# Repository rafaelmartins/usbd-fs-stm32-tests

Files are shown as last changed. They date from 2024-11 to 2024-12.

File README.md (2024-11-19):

# usbd-fs-stm32-tests

Integration tests for [usbd-fs-stm32](https://github.com/rafaelmartins/usbd-fs-stm32) library.

This repository contains the whole infrastructure required to test the library in real hardware:

- Raspberry PI Hat [PCB](./pcb) and [3D models](./3d-models)
- [Test Runner](./runner)
- [Test Firmware](./firmware) *(TODO)*
- [Github Action](./action.yml) used by main [usbd-fs-stm32 repository](https://github.com/rafaelmartins/usbd-fs-stm32) *(TODO)*

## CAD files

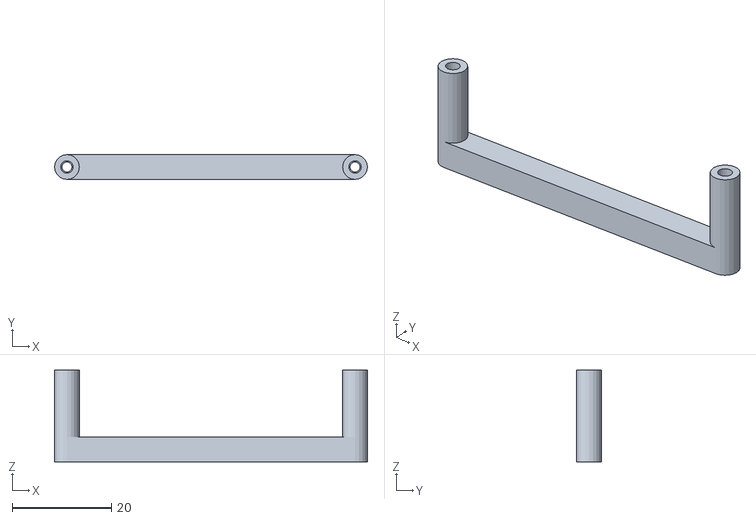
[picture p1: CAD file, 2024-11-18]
3d-models/pcb-rpi-support.stl
63.0 x 5.00 x 18.5

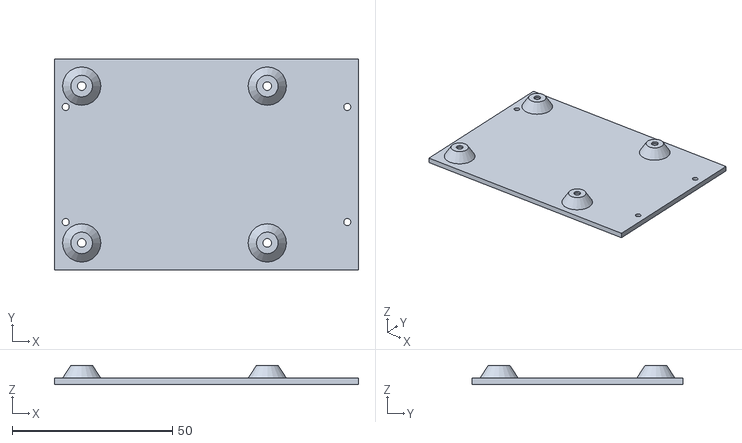
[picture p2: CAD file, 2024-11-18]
3d-models/rpi-base.stl
95.0 x 66.0 x 6.00

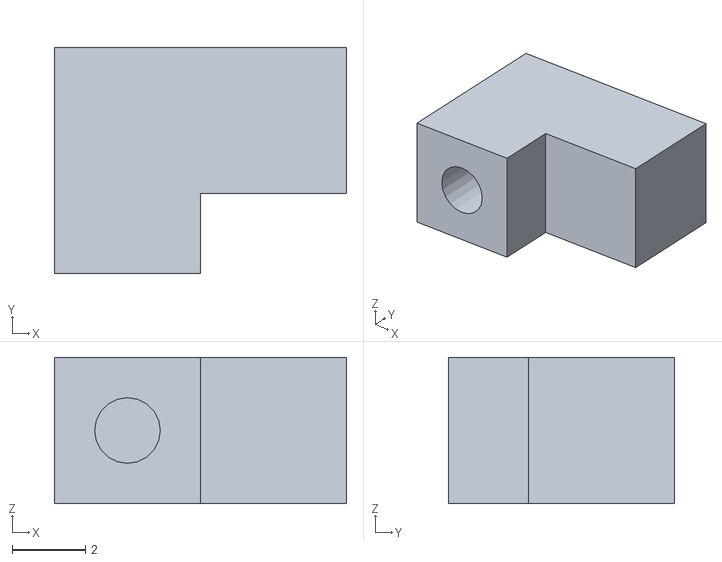
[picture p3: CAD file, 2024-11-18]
3d-models/rpi-holder.stl
8.00 x 6.20 x 4.00

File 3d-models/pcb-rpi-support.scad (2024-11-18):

// SPDX-FileCopyrightText: 2024 Rafael G. Martins <rafael@rafaelmartins.eng.br>
// SPDX-License-Identifier: CERN-OHL-S-2.0

screw_distance = 58;
screw_base_height = 18.5;
screw_base_d = 5;
screw_base_hole_top_d = 2.5;
screw_base_hole_bottom_d = 2;

difference() {
    union() {
        cylinder(h=screw_base_height, d=screw_base_d, $fn=20);
        translate([0, -screw_base_d / 2, 0])
            cube([screw_distance, screw_base_d, screw_base_d]);
        translate([screw_distance, 0, 0])
            cylinder(h=screw_base_height, d=screw_base_d, $fn=20);
    }

    cylinder(h=screw_base_height / 2, d=screw_base_hole_bottom_d, $fn=20);
    translate([0, 0, screw_base_height / 2])
        cylinder(h=screw_base_height / 2, d=screw_base_hole_top_d, $fn=20);

    translate([screw_distance, 0, 0]) {
        cylinder(h=screw_base_height / 2, d=screw_base_hole_bottom_d, $fn=20);
        translate([0, 0, screw_base_height / 2])
            cylinder(h=screw_base_height / 2, d=screw_base_hole_top_d, $fn=20);
    }
}

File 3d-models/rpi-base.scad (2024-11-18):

// SPDX-FileCopyrightText: 2024 Rafael G. Martins <rafael@rafaelmartins.eng.br>
// SPDX-License-Identifier: CERN-OHL-S-2.0

padding = 5;

length = 85 + 2 * padding;
width = 56 + 2 * padding;

screw_padding = 3.5 + padding;
screw_distance_x = 58;
screw_distance_y = 49;

holder_padding_x = 3.5;
holder_padding_y = 15;

thickness = 2;

difference() {
    union() {
        cube([length, width, thickness]);
        translate([screw_padding, screw_padding, thickness])
            for(i=[0:1])
                for(j=[0:1])
                    translate([i * screw_distance_x, j * screw_distance_y, 0])
                        cylinder(h=4, d1=12, d2=6.8, $fn=20);
    }

    translate([screw_padding, screw_padding, 0])
        for(i=[0:1])
            for(j=[0:1])
                translate([i * screw_distance_x, j * screw_distance_y, 0]) {
                    cylinder(h=thickness + 3.3, d=5.6, $fn=20);
                    cylinder(h=thickness + 4, d=2.7, $fn=20);
                }

    translate([holder_padding_x, holder_padding_y, 0])
        cylinder(h=thickness, d=2.2, $fn=20);
    translate([length - holder_padding_x, holder_padding_y, 0])
        cylinder(h=thickness, d=2.2, $fn=20);
    translate([holder_padding_x, width - holder_padding_y, 0])
        cylinder(h=thickness, d=2.2, $fn=20);
    translate([length - holder_padding_x, width - holder_padding_y, 0])
        cylinder(h=thickness, d=2.2, $fn=20);
}

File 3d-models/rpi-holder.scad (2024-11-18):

// SPDX-FileCopyrightText: 2024 Rafael G. Martins <rafael@rafaelmartins.eng.br>
// SPDX-License-Identifier: CERN-OHL-S-2.0

difference() {
    union() {
        cube([4, 2.2, 4]);
        translate([0, 2.2, 0])
            cube([8, 4, 4]);
    }

    translate([2, 0, 2])
        rotate([-90, 0, 0])
            cylinder(h=6, d=1.8, $fn=20);
}

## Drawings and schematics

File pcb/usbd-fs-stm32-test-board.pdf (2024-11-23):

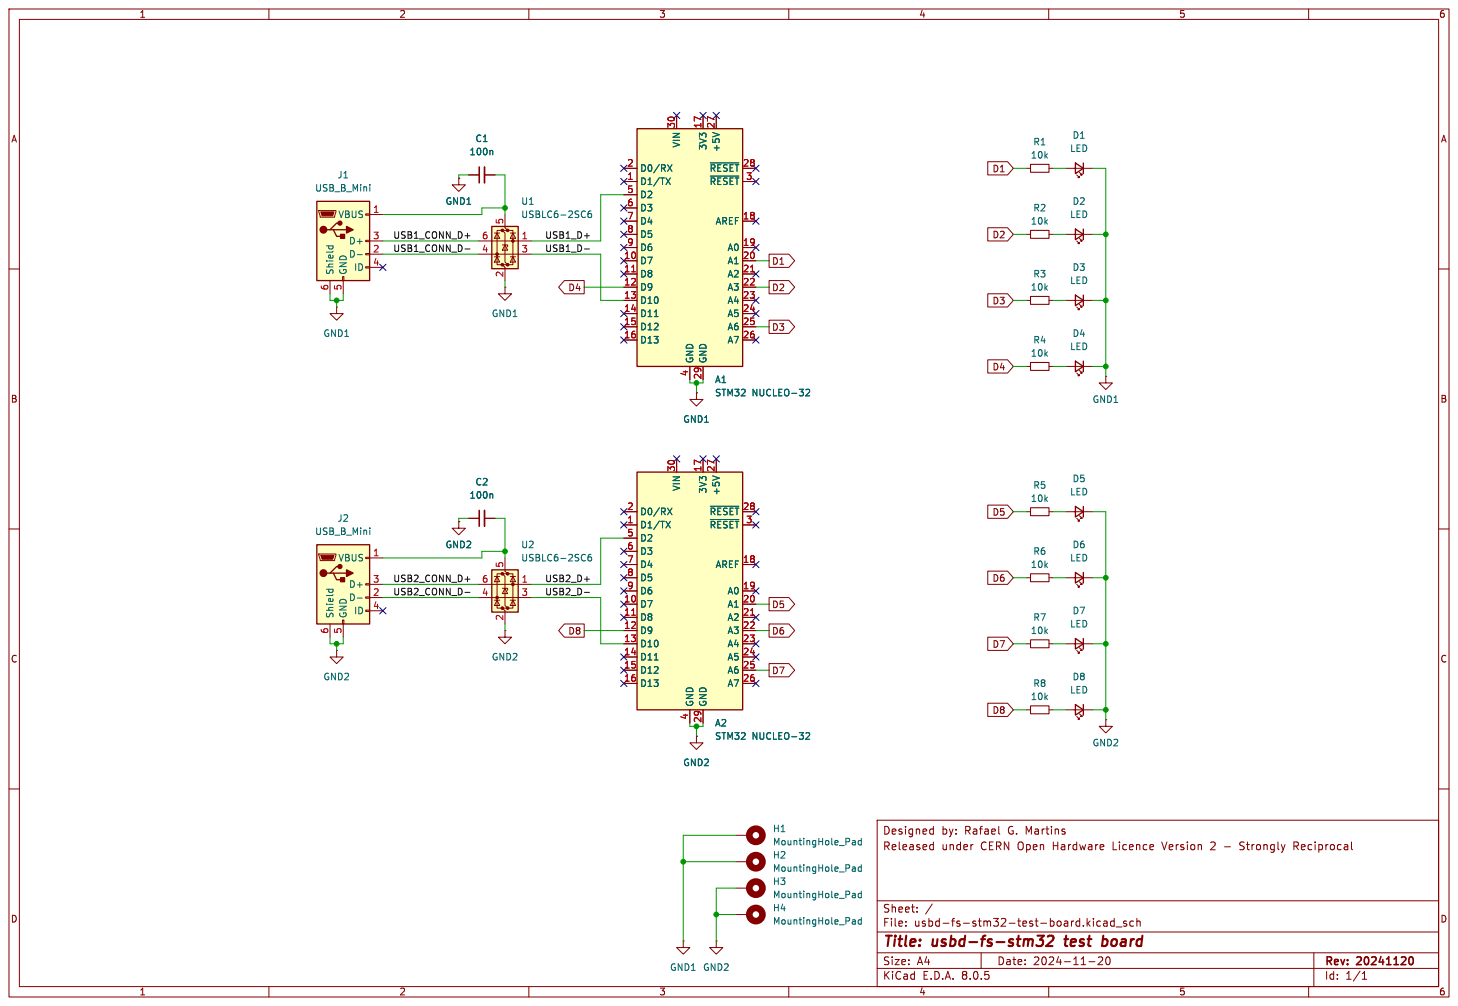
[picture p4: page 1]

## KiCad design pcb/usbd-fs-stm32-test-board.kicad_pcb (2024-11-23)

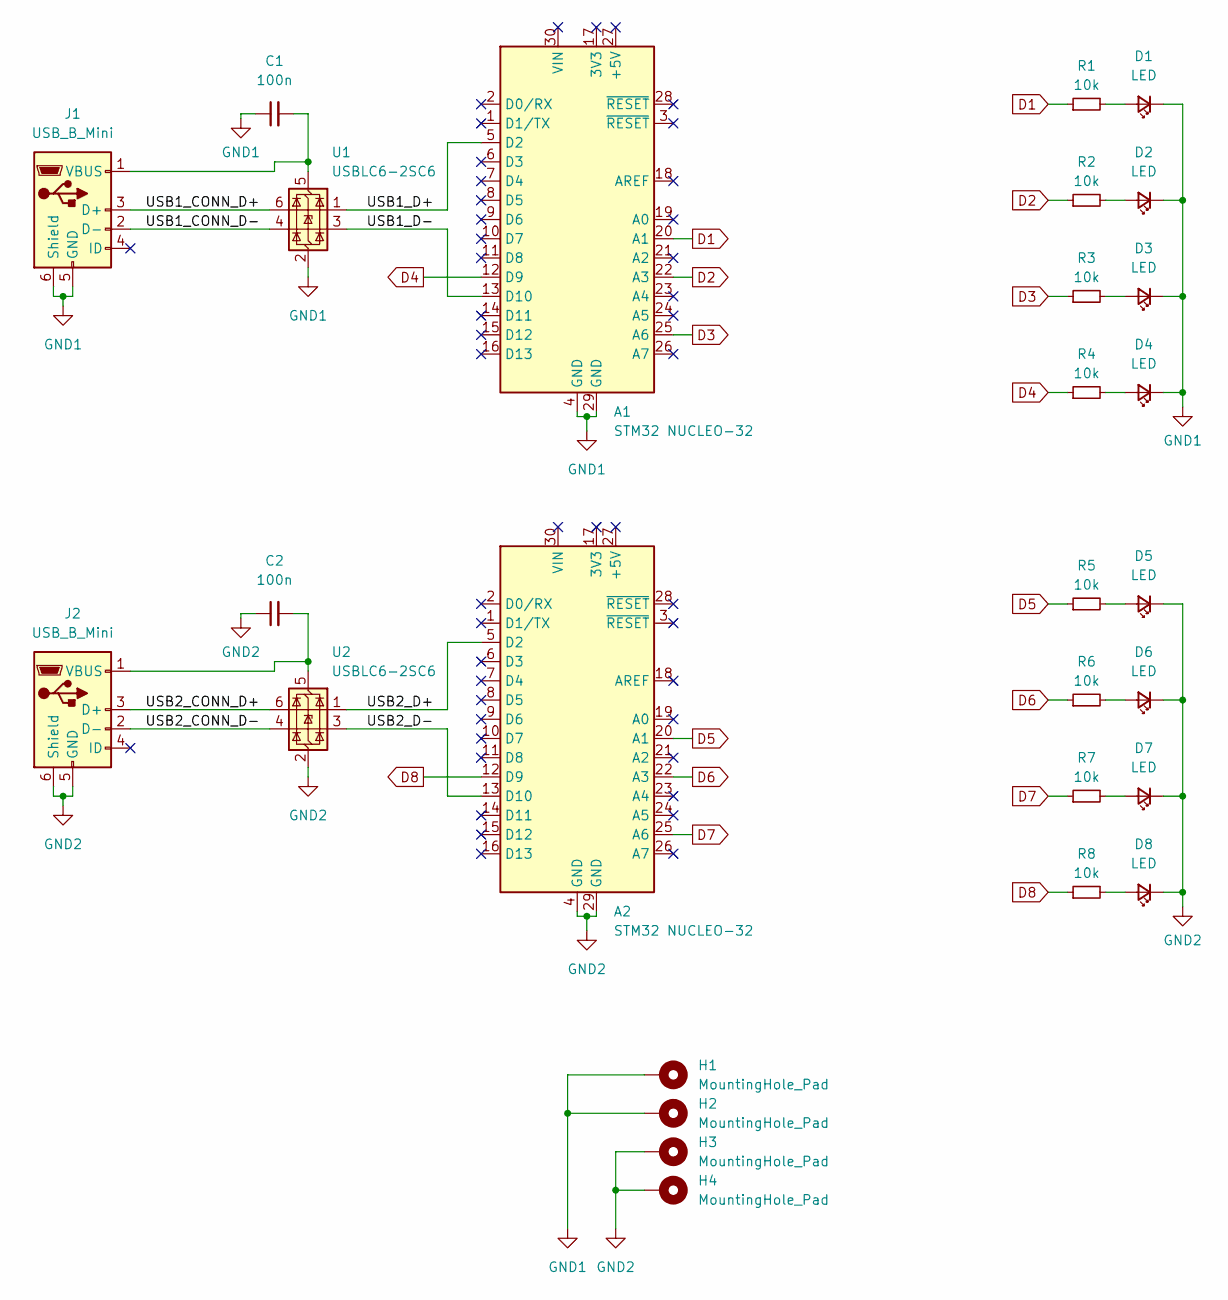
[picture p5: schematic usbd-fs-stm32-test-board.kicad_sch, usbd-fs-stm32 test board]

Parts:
A1, A2: STM32 NUCLEO-32; NUCLEO-32
C1, C2: 100n; C_TDK_FA28
D1, D2, D3, D4, D5, D6, D7, D8: LED; LED_D3.0mm
H1, H2, H3, H4: MountingHole_Pad; MountingHole_2.2mm_M2_Pad_Via
J1, J2: USB_B_Mini; USB_Mini-B_PTH
R1, R2, R3, R4, R5, R6, R7, R8: 10k; R_YAGEO_MFR-25FTE52_Horizontal
U1, U2: USBLC6-2SC6; SOT-23-6

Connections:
/USB1_CONN_D+: J1.3 (D+), U1.6 (I/O1)
/USB1_CONN_D-: J1.2 (D-), U1.4 (I/O2)
/USB1_D+: A1.5 (D2), U1.1 (I/O1)
/USB1_D-: A1.13 (D10), U1.3 (I/O2)
/USB2_CONN_D+: J2.3 (D+), U2.6 (I/O1)
/USB2_CONN_D-: J2.2 (D-), U2.4 (I/O2)
/USB2_D+: A2.5 (D2), U2.1 (I/O1)
/USB2_D-: A2.13 (D10), U2.3 (I/O2)
D1: A1.20 (A1), R1.1
D2: A1.22 (A3), R2.1
D3: A1.25 (A6), R3.1
D4: A1.12 (D9), R4.1
D5: A2.20 (A1), R5.1
D6: A2.22 (A3), R6.1
D7: A2.25 (A6), R7.1
D8: A2.12 (D9), R8.1
GND1: A1.4 (GND), A1.29 (GND), C1.1, D1.1 (K), D2.1 (K), D3.1 (K), D4.1 (K), H1.1, H2.1, J1.5 (GND), J1.6 (Shield), U1.2 (GND)
GND2: A2.4 (GND), A2.29 (GND), C2.1, D5.1 (K), D6.1 (K), D7.1 (K), D8.1 (K), H3.1, H4.1, J2.5 (GND), J2.6 (Shield), U2.2 (GND)
unnamed: D1.2 (A), R1.2
unnamed: D2.2 (A), R2.2
unnamed: D3.2 (A), R3.2
unnamed: D4.2 (A), R4.2
unnamed: D5.2 (A), R5.2
unnamed: D6.2 (A), R6.2
unnamed: D7.2 (A), R7.2
unnamed: D8.2 (A), R8.2
unnamed: C1.2, J1.1 (VBUS), U1.5 (VBUS)
unnamed: C2.2, J2.1 (VBUS), U2.5 (VBUS)

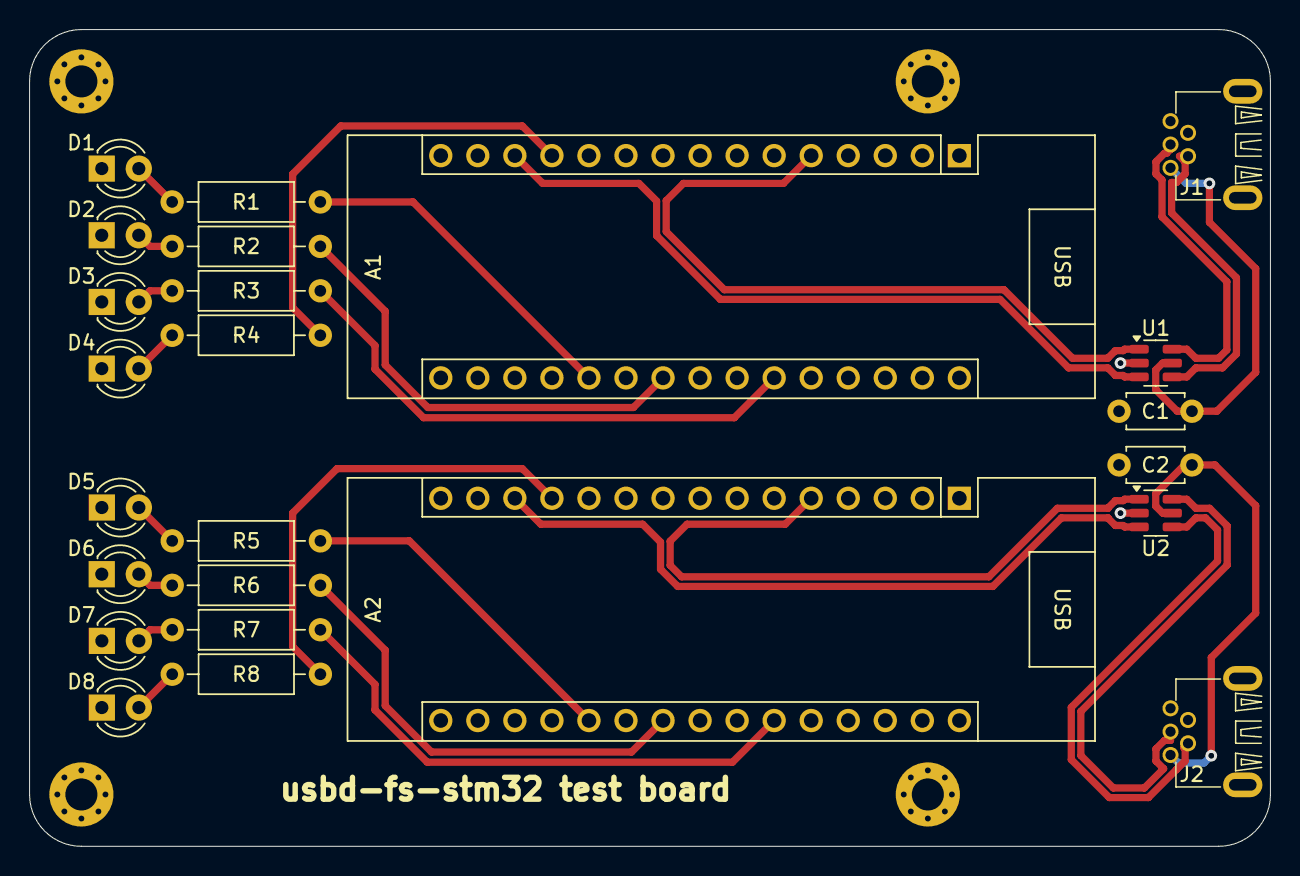
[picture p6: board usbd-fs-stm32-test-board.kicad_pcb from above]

Board: 2 copper layers, 85.1 x 56.0 mm, 28 parts (0 on the bottom side), 28 nets.

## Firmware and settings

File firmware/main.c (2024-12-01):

/*
 * SPDX-FileCopyrightText: 2024 Rafael G. Martins <rafael@rafaelmartins.eng.br>
 * SPDX-License-Identifier: BSD-3-Clause
 */

#include <assert.h>
#include <stdbool.h>
#include <stdint.h>
#include <hal.h>
#include <test.h>
#include <serial-protocol.h>

#ifndef USART_BAUDRATE
#define USART_BAUDRATE 115200
#endif

extern uint8_t test_count;
static serial_proto_reply_get_test_result_t test_result = PROTO_REPLY_GET_TEST_RESULT_PASSED;


void
test_fail(void)
{
    test_result = PROTO_REPLY_GET_TEST_RESULT_FAILED;
}


static inline void
serial_send_byte(char c)
{
    while ((USART_REG->ISR & USART_ISR_TXE) != USART_ISR_TXE);
    USART_REG->TDR = c;
}


int
main(void)
{
    hal_clock_init();

    RCC->GPIO_RCC |= GPIO_RCC_EN(GPIO_RCC, BOARD_LED_BLK) | GPIO_RCC_EN(GPIO_RCC, TEST_LEDS_BLK);

    BOARD_LED_REG->MODER &= ~(GPIO_MODER_MASK(BOARD_LED_IDX));
    BOARD_LED_REG->MODER |= GPIO_MODER_OUTPUT(BOARD_LED_IDX);
    board_led_reset();

    TEST_LEDS_REG->MODER &= ~(GPIO_MODER_MASK(TEST_LED1_IDX) | GPIO_MODER_MASK(TEST_LED2_IDX) |
                              GPIO_MODER_MASK(TEST_LED3_IDX) | GPIO_MODER_MASK(TEST_LED4_IDX));
    TEST_LEDS_REG->MODER |= GPIO_MODER_OUTPUT(TEST_LED1_IDX) | GPIO_MODER_OUTPUT(TEST_LED2_IDX) |
                            GPIO_MODER_OUTPUT(TEST_LED3_IDX) | GPIO_MODER_OUTPUT(TEST_LED4_IDX);
    test_leds_reset(TEST_LEDS);

    RCC->GPIO_RCC  |= GPIO_RCC_EN(GPIO_RCC, USART_BLK);
    RCC->USART_RCC |= USART_RCC_EN(USART_RCC, USART_IDX);

    USART_GPIO_REG->OTYPER |= GPIO_OTYPER_OT(USART_TX_IDX) | GPIO_OTYPER_OT(USART_RX_IDX);
    USART_GPIO_REG->PUPDR &= ~(GPIO_PUPDR_PUPD_MASK(USART_TX_IDX) | GPIO_PUPDR_PUPD_MASK(USART_RX_IDX));
    USART_GPIO_REG->PUPDR |= GPIO_PUPDR_PUPD_UP(USART_TX_IDX) | GPIO_PUPDR_PUPD_UP(USART_RX_IDX);
    USART_GPIO_REG->MODER &= ~(GPIO_MODER_MASK(USART_TX_IDX) | GPIO_MODER_MASK(USART_RX_IDX));
    USART_GPIO_REG->MODER |= GPIO_MODER_ALTERNATE(USART_TX_IDX) | GPIO_MODER_ALTERNATE(USART_RX_IDX);
    USART_GPIO_REG->AFR[USART_TX_AFR_IDX] &= ~(GPIO_AFR_AFSEL_MASK(USART_TX_AFR_REG, USART_TX_IDX));
    USART_GPIO_REG->AFR[USART_TX_AFR_IDX] |= GPIO_AFR_AFSEL_USART(USART_TX_AFR_REG, USART_TX_IDX);
    USART_GPIO_REG->AFR[USART_RX_AFR_IDX] &= ~(GPIO_AFR_AFSEL_MASK(USART_RX_AFR_REG, USART_RX_IDX));
    USART_GPIO_REG->AFR[USART_RX_AFR_IDX] |= GPIO_AFR_AFSEL_USART(USART_RX_AFR_REG, USART_RX_IDX);

    USART_REG->BRR = (uint16_t) (SystemCoreClock / USART_BAUDRATE);
    USART_REG->CR3 = USART_CR3_ONEBIT;
    USART_REG->CR1 = USART_CR1_TE | USART_CR1_RE | USART_CR1_UE | USART_CR1_RXNEIE;

    while (((USART_REG->ISR & USART_ISR_REACK) != USART_ISR_REACK) &&
           ((USART_REG->ISR & USART_ISR_TEACK) != USART_ISR_TEACK));

    if (test_init)
        test_init();

    while (true) {
        if ((USART_REG->ISR & USART_ISR_RXNE) == USART_ISR_RXNE) {
            uint8_t reg = USART_REG->RDR;
            uint8_t cmd = reg & 0xf0;
            uint8_t val = reg & 0x0f;

            switch ((serial_proto_cmd_t) (cmd >> 4)) {
            case PROTO_CMD_CONFIGURE_TEST:
                if (val == 0 || val > test_count) {
                    serial_send_byte(cmd | PROTO_REPLY_CONFIGURE_TEST_INVALID_ID);
                    break;
                }
                test_result = PROTO_REPLY_GET_TEST_RESULT_PASSED;
                serial_send_byte(cmd | (test_configure(val) ?
                    PROTO_REPLY_CONFIGURE_TEST_OK : PROTO_REPLY_CONFIGURE_TEST_FAILED));
                break;

            case PROTO_CMD_GET_TEST_COUNT:
                serial_send_byte(cmd | (test_count & 0x0f));
                break;

            case PROTO_CMD_GET_TEST_RESULT:
                serial_send_byte(cmd | test_result);
                break;

            case PROTO_CMD_SYNC:
                switch ((serial_proto_cmd_sync_t) val) {
                case PROTO_CMD_SYNC_VAL_SYNC:
                    serial_send_byte(reg);
                    break;
                }
                break;
            }
            continue;
        }

        if (test_loop)
            test_loop();
    }

    return 0;
}

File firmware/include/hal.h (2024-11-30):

/*
 * SPDX-FileCopyrightText: 2024 Rafael G. Martins <rafael@rafaelmartins.eng.br>
 * SPDX-License-Identifier: BSD-3-Clause
 */

#pragma once

#if defined(STM32F042x6)
#include <stm32f0xx.h>

#define GPIO_RCC AHBENR

#define _GPIO_BSRR_BS(idx)          GPIO_BSRR_BS_ ## idx
#define _GPIO_BSRR_BR(idx)          GPIO_BSRR_BR_ ## idx
#define _GPIO_MODER_MASK(idx)       GPIO_MODER_MODER ## idx
#define _GPIO_MODER_OUTPUT(idx)     GPIO_MODER_MODER ## idx ## _0
#define _GPIO_MODER_ALTERNATE(idx)  GPIO_MODER_MODER ## idx ## _1
#define _GPIO_OTYPER_OT(idx)        GPIO_OTYPER_OT_ ## idx
#define _GPIO_PUPDR_PUPD_MASK(idx)  GPIO_PUPDR_PUPDR ## idx
#define _GPIO_PUPDR_PUPD_UP(idx)    GPIO_PUPDR_PUPDR ## idx ## _0
#define _GPIO_AFRH_AFSEL_MASK(idx)  GPIO_AFRH_AFSEL ## idx
#define _GPIO_AFRH_AFSEL_USART(idx) (0b1 << GPIO_AFRH_AFSEL ## idx ## _Pos)
#define _GPIO_AFRL_AFSEL_MASK(idx)  GPIO_AFRL_AFSEL ## idx
#define _GPIO_AFRL_AFSEL_USART(idx) (0b1 << GPIO_AFRL_AFSEL ## idx ## _Pos)

#define BOARD_LED_BLK B
#define BOARD_LED_IDX 3

#define TEST_LEDS_BLK A
#define TEST_LED1_IDX 1
#define TEST_LED2_IDX 4
#define TEST_LED3_IDX 7
#define TEST_LED4_IDX 8

#define USART_RCC APB1ENR

#define USART_BLK        A
#define USART_IDX        2
#define USART_TX_IDX     2
#define USART_TX_AFR_IDX 0
#define USART_TX_AFR_REG L
#define USART_RX_IDX     15
#define USART_RX_AFR_IDX 1
#define USART_RX_AFR_REG H

static inline void
hal_clock_init(void)
{
    // 1 flash wait cycle required to operate @ 48MHz (RM0091 section 3.5.1)
    FLASH->ACR &= ~FLASH_ACR_LATENCY;
    FLASH->ACR |= FLASH_ACR_LATENCY;
    while ((FLASH->ACR & FLASH_ACR_LATENCY) != FLASH_ACR_LATENCY);

    RCC->CR2 |= RCC_CR2_HSI48ON;
    while ((RCC->CR2 & RCC_CR2_HSI48RDY) != RCC_CR2_HSI48RDY);

    RCC->CFGR &= ~(RCC_CFGR_HPRE | RCC_CFGR_PPRE | RCC_CFGR_SW);
    RCC->CFGR |= RCC_CFGR_HPRE_DIV1 | RCC_CFGR_PPRE_DIV1 | RCC_CFGR_SW_HSI48;
    while((RCC->CFGR & RCC_CFGR_SWS) != RCC_CFGR_SWS_HSI48);

    SystemCoreClock = 48000000;
}

#elif defined(STM32G431xx)
#include <stm32g4xx.h>

#define GPIO_RCC AHB2ENR

#define _GPIO_BSRR_BS(idx)          GPIO_BSRR_BS ## idx
#define _GPIO_BSRR_BR(idx)          GPIO_BSRR_BR ## idx
#define _GPIO_MODER_MASK(idx)       GPIO_MODER_MODE ## idx
#define _GPIO_MODER_OUTPUT(idx)     GPIO_MODER_MODE ## idx ## _0
#define _GPIO_MODER_ALTERNATE(idx)  GPIO_MODER_MODE ## idx ## _1
#define _GPIO_OTYPER_OT(idx)        GPIO_OTYPER_OT ## idx
#define _GPIO_PUPDR_PUPD_MASK(idx)  GPIO_PUPDR_PUPD ## idx
#define _GPIO_PUPDR_PUPD_UP(idx)    GPIO_PUPDR_PUPD ## idx ## _0
#define _GPIO_AFRH_AFSEL_MASK(idx)  GPIO_AFRH_AFSEL ## idx
#define _GPIO_AFRH_AFSEL_USART(idx) (GPIO_AFRH_AFSEL ## idx ## _0 | GPIO_AFRH_AFSEL ## idx ## _1 | GPIO_AFRH_AFSEL ## idx ## _2)
#define _GPIO_AFRL_AFSEL_MASK(idx)  GPIO_AFRL_AFSEL ## idx
#define _GPIO_AFRL_AFSEL_USART(idx) (GPIO_AFRL_AFSEL ## idx ## _0 | GPIO_AFRL_AFSEL ## idx ## _1 | GPIO_AFRL_AFSEL ## idx ## _2)

#define BOARD_LED_BLK B
#define BOARD_LED_IDX 8

#define TEST_LEDS_BLK A
#define TEST_LED1_IDX 1
#define TEST_LED2_IDX 4
#define TEST_LED3_IDX 7
#define TEST_LED4_IDX 8

#define USART_RCC APB1ENR1

#define USART_BLK        A
#define USART_IDX        2
#define USART_TX_IDX     2
#define USART_TX_AFR_IDX 0
#define USART_TX_AFR_REG L
#define USART_RX_IDX     3
#define USART_RX_AFR_IDX 0
#define USART_RX_AFR_REG L

static inline void
hal_clock_init(void)
{
    // 4 flash wait cycles required to operate @ 170MHz (RM0440 section 5.3.3 table 29)
    FLASH->ACR &= ~FLASH_ACR_LATENCY;
    FLASH->ACR |= FLASH_ACR_LATENCY_4WS;  // RM0440 5.3.3
    while ((FLASH->ACR & FLASH_ACR_LATENCY) != FLASH_ACR_LATENCY_4WS);

    // regulator boost mode required to operate @ 170MHz (RM0440 section 6.1.5 table 38)
    PWR->CR5 &= ~PWR_CR5_R1MODE;

    RCC->CR |= RCC_CR_HSION;
    while ((RCC->CR & RCC_CR_HSIRDY) != RCC_CR_HSIRDY);

    RCC->CRRCR |= RCC_CRRCR_HSI48ON;
    while ((RCC->CRRCR & RCC_CRRCR_HSI48RDY) != RCC_CRRCR_HSI48RDY);

    // pll configuration (RM0440 section 7.4.4)
    //      f(PLL_R) = F(HSE/HSI) * PLLN / (PLLM * PLLR)
    //
    // HSE:
    //      24e6 * 85 / (2 * 6) = 170e6
    // HSI:
    //      16e6 * 85 / (2 * 4) = 170e6
    RCC->PLLCFGR = (85 << RCC_PLLCFGR_PLLN_Pos) |  // 0b00: PLLR = 2 (RM0440 section 7.4.4)
        RCC_PLLCFGR_PLLSRC_HSI | RCC_PLLCFGR_PLLM_1 | RCC_PLLCFGR_PLLM_0;  // 0b0011: PLLM = 4

    RCC->PLLCFGR |= RCC_PLLCFGR_PLLREN;
    RCC->CR |= RCC_CR_PLLON;
    while ((RCC->CR & RCC_CR_PLLRDY) != RCC_CR_PLLRDY);

    // to switch to the high speed 170MHz clock, it is recommended to put
    // system clock into an intermediate frequency, for at least 1us.
    // run @ 85MHz by setting AHB prescaler to 2.
    RCC->CFGR &= ~RCC_CFGR_SW;
    RCC->CFGR |= RCC_CFGR_SW_PLL | RCC_CFGR_HPRE_DIV2;
    while ((RCC->CFGR & RCC_CFGR_SWS) != RCC_CFGR_SWS_PLL);

    // by iterating 85 times @ 170MHz and assuming that each iteration takes
    // at least two cycles (in practice it takes more), this loop will take at
    // least 1us
    for (__IO uint32_t i = 85; i; i--);

    // disable AHB prescaler.
    RCC->CFGR &= ~RCC_CFGR_HPRE;
    RCC->CFGR |= RCC_CFGR_HPRE_DIV1;

    SystemCoreClock = 170000000;
}

#else
#error "Unsupported microcontroller."
#endif

#define _GPIO_RCC_EN(reg, block)          RCC_ ## reg ## _GPIO ## block ## EN
#define GPIO_RCC_EN(reg, block)           _GPIO_RCC_EN(reg, block)
#define _GPIO_REG(block)                  GPIO ## block
#define GPIO_REG(block)                   _GPIO_REG(block)
#define GPIO_BSRR_BS(idx)                 _GPIO_BSRR_BS(idx)
#define GPIO_BSRR_BR(idx)                 _GPIO_BSRR_BR(idx)
#define GPIO_MODER_MASK(idx)              _GPIO_MODER_MASK(idx)
#define GPIO_MODER_OUTPUT(idx)            _GPIO_MODER_OUTPUT(idx)
#define GPIO_MODER_ALTERNATE(idx)         _GPIO_MODER_ALTERNATE(idx)
#define GPIO_OTYPER_OT(idx)               _GPIO_OTYPER_OT(idx)
#define GPIO_PUPDR_PUPD_MASK(idx)         _GPIO_PUPDR_PUPD_MASK(idx)
#define GPIO_PUPDR_PUPD_UP(idx)           _GPIO_PUPDR_PUPD_UP(idx)
#define _GPIO_AFR_AFSEL_MASK(block, idx)  _GPIO_AFR ## block ## _AFSEL_MASK(idx)
#define GPIO_AFR_AFSEL_MASK(block, idx)   _GPIO_AFR_AFSEL_MASK(block, idx)
#define _GPIO_AFR_AFSEL_USART(block, idx) _GPIO_AFR ## block ## _AFSEL_USART(idx)
#define GPIO_AFR_AFSEL_USART(block, idx)  _GPIO_AFR_AFSEL_USART(block, idx)

#define _USART_RCC_EN(reg, idx) RCC_ ## reg ## _USART ## idx ## EN
#define USART_RCC_EN(reg, idx)  _USART_RCC_EN(reg, idx)
#define __USART_REG(idx)        USART ## idx
#define _USART_REG(idx)         __USART_REG(idx)
#define USART_REG               _USART_REG(USART_IDX)

#define BOARD_LED_REG  GPIO_REG(BOARD_LED_BLK)
#define TEST_LEDS_REG  GPIO_REG(TEST_LEDS_BLK)
#define USART_GPIO_REG GPIO_REG(USART_BLK)
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

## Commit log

2024-11-18 Initial commit
    I have this PCB waiting on my desk for months but finally assembled it.
    Let's get things started!
    [pcb-rpi-support.scad, pcb-rpi-support.stl, rpi-base.scad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]
2024-11-19 runner: enable warnings and convert to error
    [main.c]
2024-11-20 firmware: link against usbd-fs-stm32, move tests to root
2024-11-23 pcb: revision 20241120: fixed conflict of LED pins with VCP pins
    [usbd-fs-stm32-test-board.kicad_pcb, usbd-fs-stm32-test-board.kicad_sch]
2024-11-23 firmware: changes to support pcb revision 20241120
2024-12-01 allow test firmware to mark test as failed
    also rewrite most of the stlink implementation to not reuse connections
    and halt the devices after running tests.
    [main.c]

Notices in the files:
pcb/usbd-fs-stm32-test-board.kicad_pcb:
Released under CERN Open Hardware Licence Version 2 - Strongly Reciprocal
